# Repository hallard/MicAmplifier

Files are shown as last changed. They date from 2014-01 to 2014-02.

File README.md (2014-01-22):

Universal Stereo MIC/Line amplifier for Audio processing with ADC
================================================================

This is a simple board to amplifiy stereo mic or ligne signal to be processed
by a analog entry of a microcontroller.

It can be used for processing audio and lit LED strip for example or whatever,
the input signal can come from electret microphone, standard microphone,
line out or any jack audio output of any device.

Schematics were strongly took and inspired from [coolarduino][1] site 
and the [vu meter 1][2] [vu meter 2][3] topic and schematics

Check out news and other projects on my [blog][4]

Detailed Description
====================

Everything will be documented on my[blog][4]

**Schematic**  
schematic

**Board**  
board

top&nbsp;&nbsp;bottom

[1]: http://coolarduino.wordpress.com/
[2]: http://coolarduino.wordpress.com/2012/06/28/stereo-audio-vu-meter-on-arduino/
[3]: http://coolarduino.wordpress.com/2012/07/01/audio-vu-meter-ac-micro-voltmeter-with-extra-wide-dynamic-range-72-db/
[4]: http://hallard.me

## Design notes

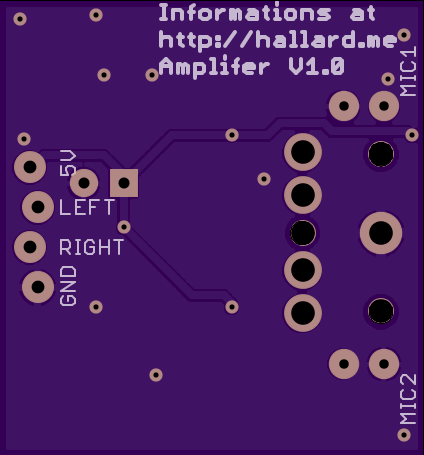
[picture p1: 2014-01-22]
MicAmplifier-bottom.png

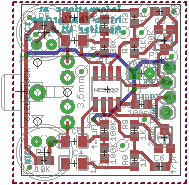
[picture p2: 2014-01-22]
MicAmplifier-brd.png

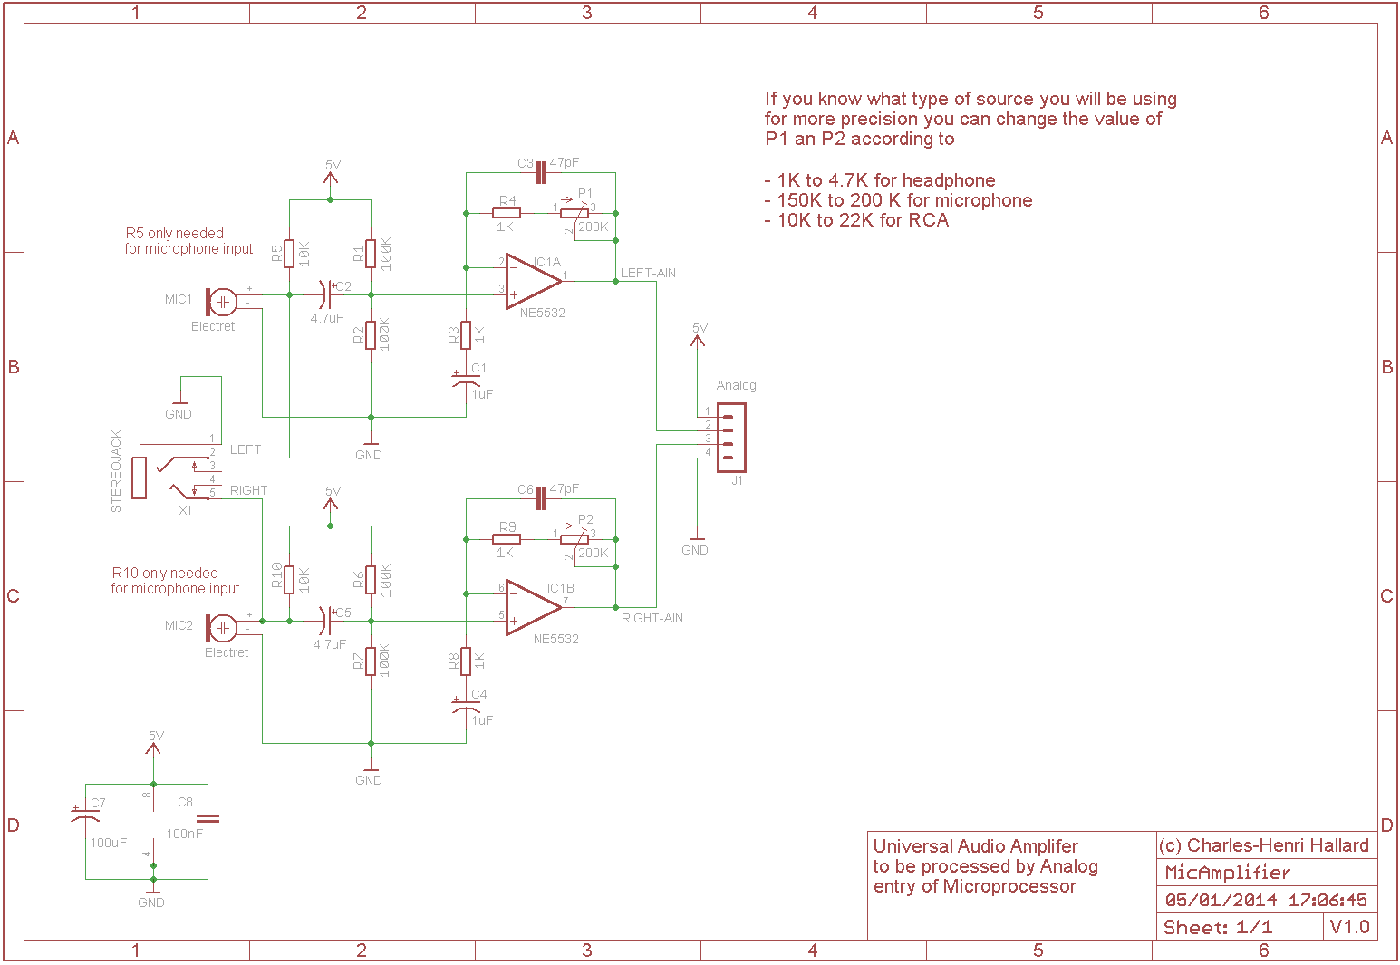
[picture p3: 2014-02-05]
MicAmplifier-sch.png

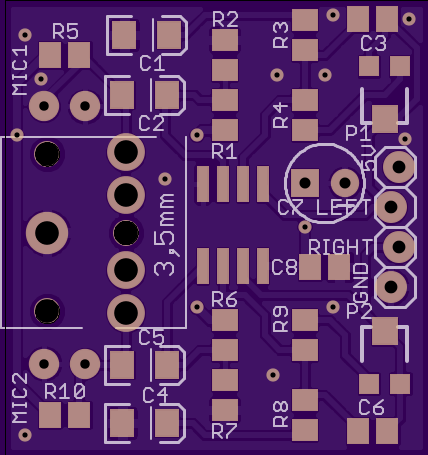
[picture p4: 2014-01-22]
MicAmplifier-top.png

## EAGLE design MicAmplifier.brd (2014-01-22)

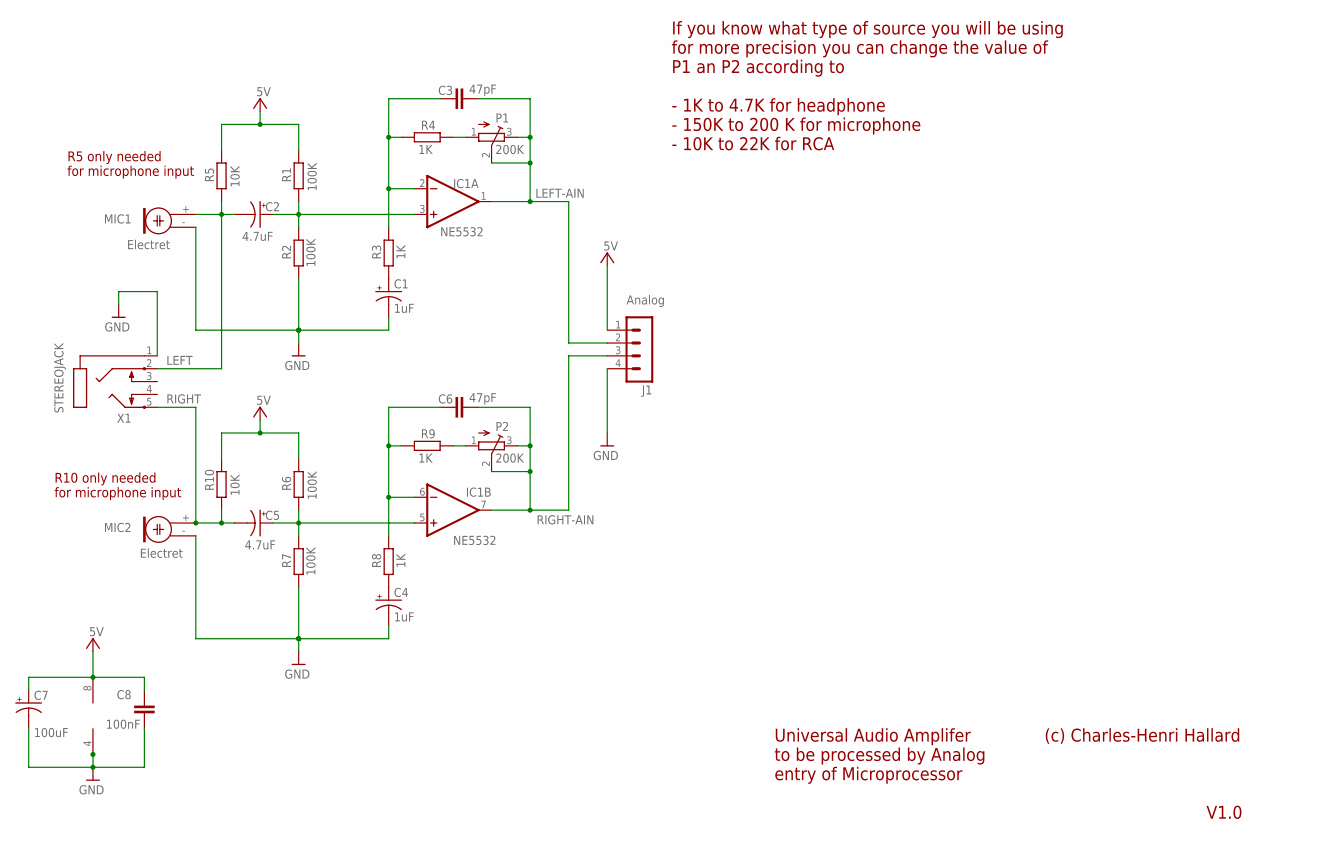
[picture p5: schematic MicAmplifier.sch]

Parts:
C1, C4: 1uF; EIA3216
C2, C5: 4.7uF; EIA3216
C3, C6: 47pF; C805
C7: 100uF; CPOL-RADIAL-10UF-25V
C8: 100nF; C805
IC1: NE5532; SO08
J1: Analog; 1X04_LOCK
MIC1, MIC2: Electret; 9.7ELECTRET
P1, P2: 200K; TC33X
R1, R2, R6, R7: 100K; R805
R3, R4, R8, R9: 1K; R805
R5, R10: 10K; R805
X1: STEREOJACK; STX3100

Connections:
+5V: C7.1 (+), C8.2, IC1.8 (V+), J1.1, R1.2, R5.2, R6.2, R10.2
GND: C1.C (-), C4.C (-), C7.2 (-), C8.1, IC1.4 (V-), J1.4, MIC1.- (1), MIC2.- (1), R2.1, R7.1, X1.1
LEFT: C2.C (-), MIC1.+ (2), R5.1, X1.2
LEFT-AIN: C3.2, IC1.1 (OUT), J1.2, P1.2 (S), P1.3 (E)
unnamed: C2.A (+), IC1.3 (+IN), R1.1, R2.2
unnamed: C1.A (+), R3.1
unnamed: C3.1, IC1.2 (-IN), R3.2, R4.1
unnamed: C5.A (+), IC1.5 (+IN), R6.1, R7.2
unnamed: P1.1 (A), R4.2
unnamed: C4.A (+), R8.1
unnamed: C6.1, IC1.6 (-IN), R8.2, R9.1
unnamed: P2.1 (A), R9.2
RIGHT: C5.C (-), MIC2.+ (2), R10.1, X1.5
RIGHT-AIN: C6.2, IC1.7 (OUT), J1.3, P2.2 (S), P2.3 (E)

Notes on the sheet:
Universal Audio Amplifer to be processed by Analog entry of Microprocessor
(c) Charles-Henri Hallard
If you know what type of source you will be using for more precision you can change the value of P1 an P2 according to
- 1K to 4.7K for headphone - 150K to 200 K for microphone - 10K to 22K for RCA
R5 only needed for microphone input
R10 only needed for microphone input
V1.0

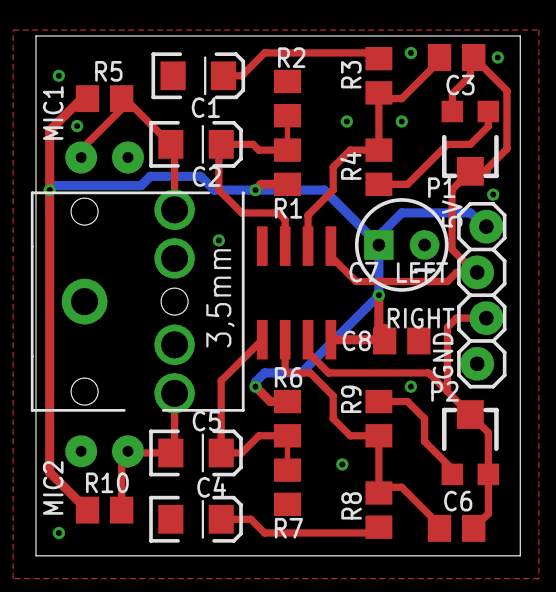
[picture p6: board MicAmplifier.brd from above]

Board: 2 copper layers, 26.9 x 28.9 mm, 25 parts (0 on the bottom side), 14 nets.

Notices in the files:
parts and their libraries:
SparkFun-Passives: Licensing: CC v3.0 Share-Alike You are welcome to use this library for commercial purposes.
